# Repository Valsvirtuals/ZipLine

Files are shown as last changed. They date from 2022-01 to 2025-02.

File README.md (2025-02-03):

# ZipLine
Cheap and relatively easy to build finger tracking glove for vr
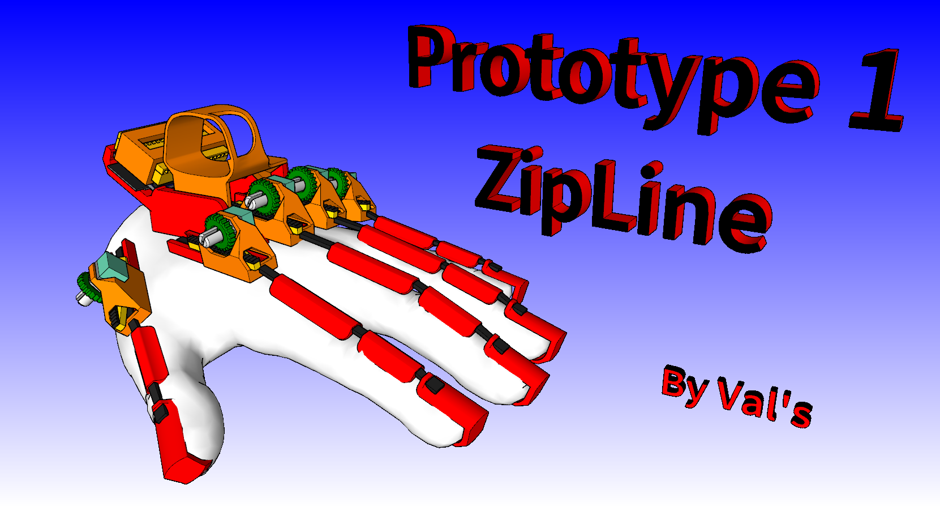
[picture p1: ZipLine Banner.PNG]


this project uses the lucid glçove firmware: https://github.com/LucidVR/lucidgloves
and the openglove driver: https://store.steampowered.com/app/1574050/OpenGloves/

/!\ THIS IS AN EALY PROTOTYPE /!\

it's far from perfect. if you just want a glove that work, this aint' it!
you've been warned.

i don't take any responsibility in your disapointment.

if you have any question don't hesitate to come and aks on my discord server in the LimenVR > #harware-help channel

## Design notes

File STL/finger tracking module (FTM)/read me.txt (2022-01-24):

dovetail parts (way & slide) sould be printed with cura ironing feature, or sililar from other slicer

the gear sould be printed at around 10mm/s print speed to preserve details

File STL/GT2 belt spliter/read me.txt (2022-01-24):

assembly:

-print the 2 parts
-glue them together
-stick a 9mm utility knife blade thought the slot, leading edge on the narrower side

usage:

-start the cut by sliting end of the belt in two
-push the plit end thought the spliter jig
-pull from the other side

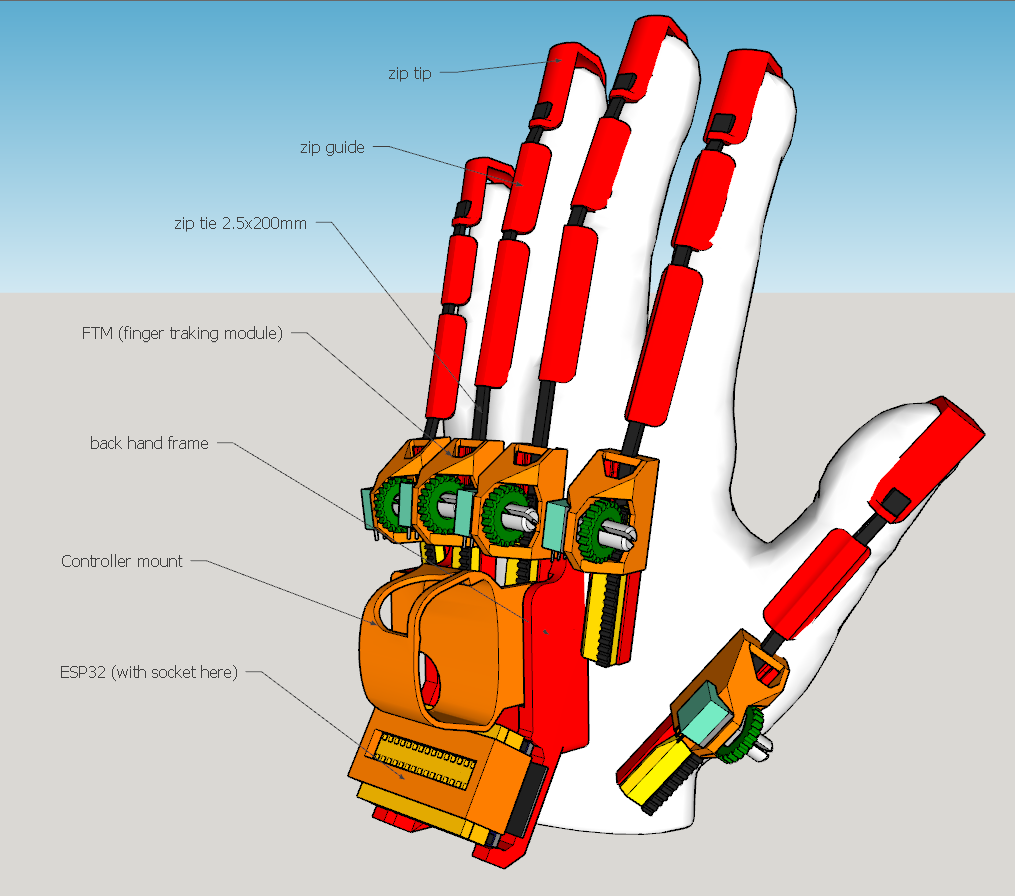
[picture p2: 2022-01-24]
description glove.PNG

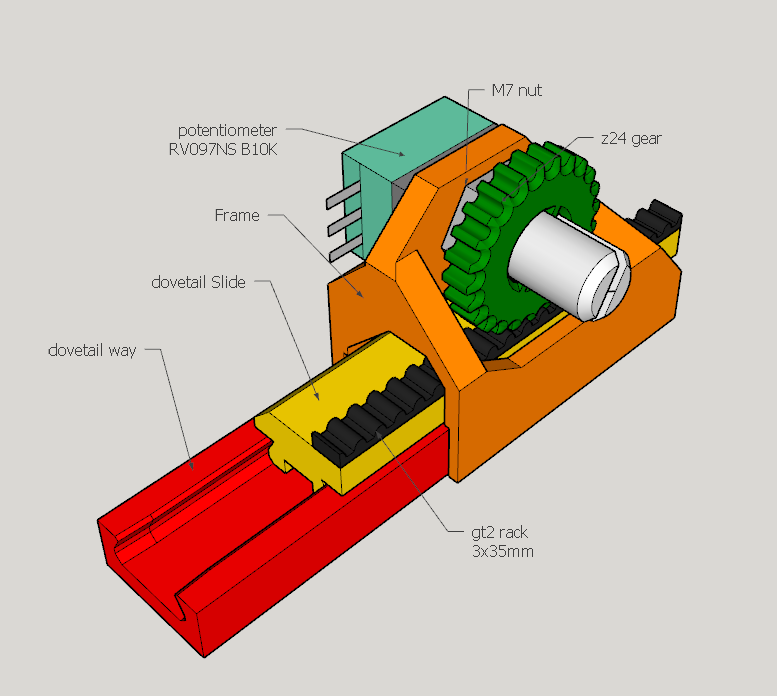
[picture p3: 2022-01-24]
description finger tracking module.PNG

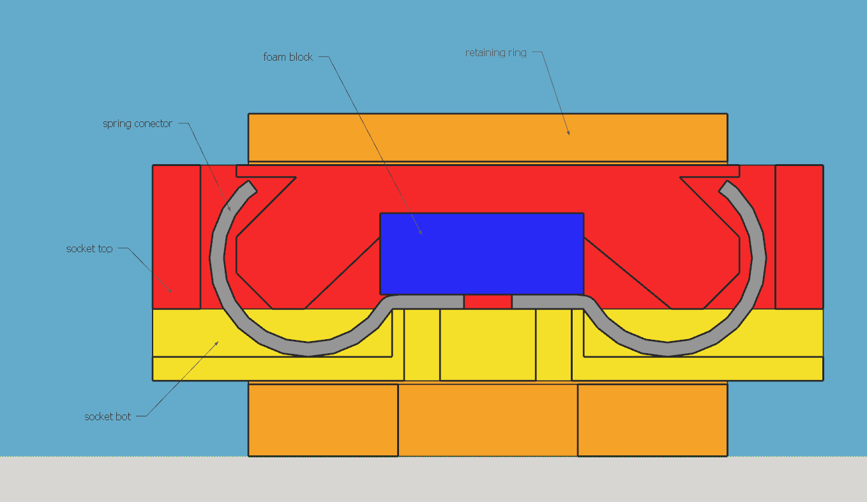
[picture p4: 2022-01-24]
ESP32 socket (optional)/socket section plane.PNG

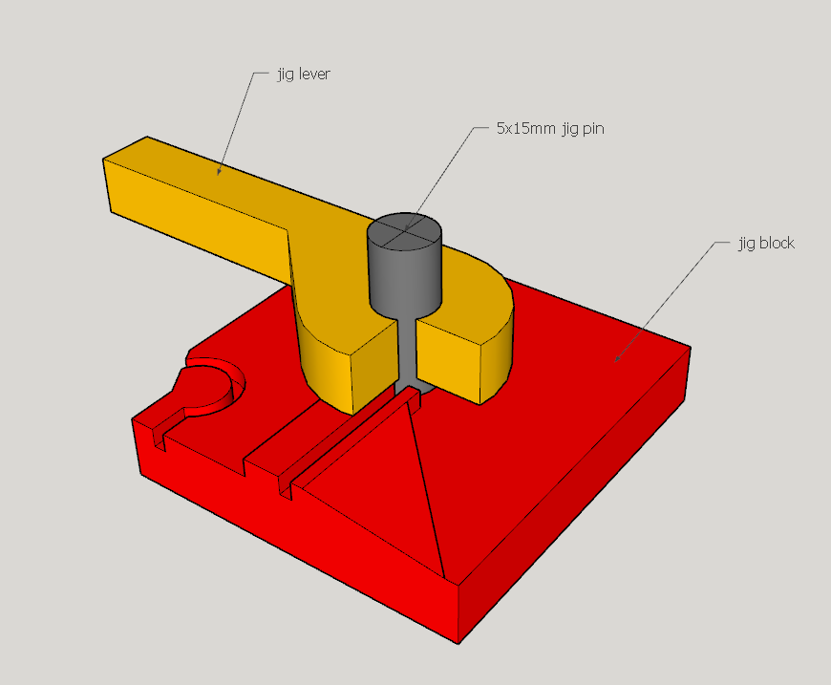
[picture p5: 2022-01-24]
ESP32 socket (optional)/connector bending and cutting jig jig.PNG

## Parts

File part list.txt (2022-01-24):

for 1 glove

what you need to get:
- Nylon glove (need to be quite thin and fit thightly on your hand)
-1x ESP32 Wroom DevKit Board
-5x RV097NS B10K Potentiometers (with nut and washer)
-5x 2.5x200mm zip ties (2.5x150mm is enough for smaller hands)

what you need to print:
-5x zip tip
-9x zip guides (chose the right size for each knuckles and fingertips)

-5x Finger tracking module:
   -5x dovetail way    (print with ironing)
   -5x dovetail slide  (print with ironing)
   -5x frames
   -5x z24 gears       (10mm/s print speed)

-1x Back Hand Frame
-1x Controller mount (windows mr or you can edit blank controller mount to fit your's)

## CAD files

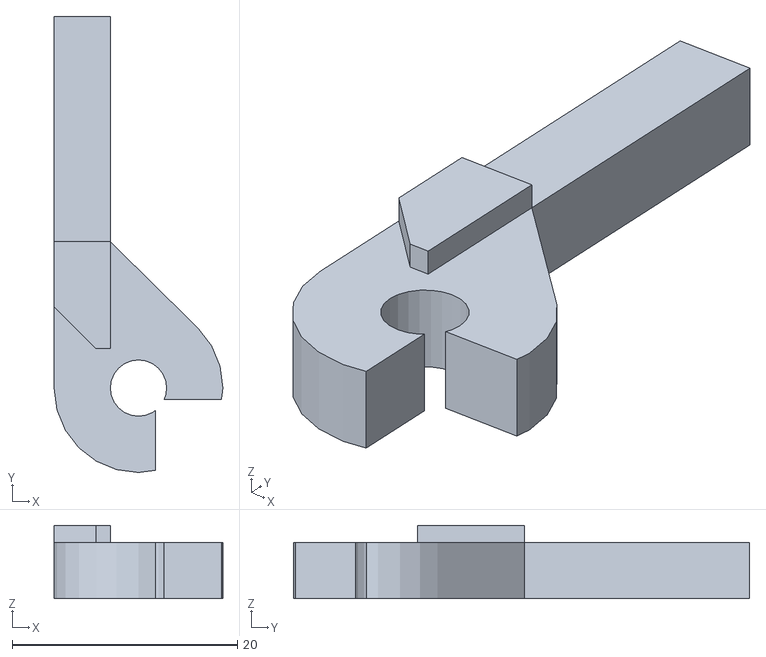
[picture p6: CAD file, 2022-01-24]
ESP32 socket (optional)/STL/Jig/esp32 socket jig lever.stl
15.0 x 40.5 x 6.50

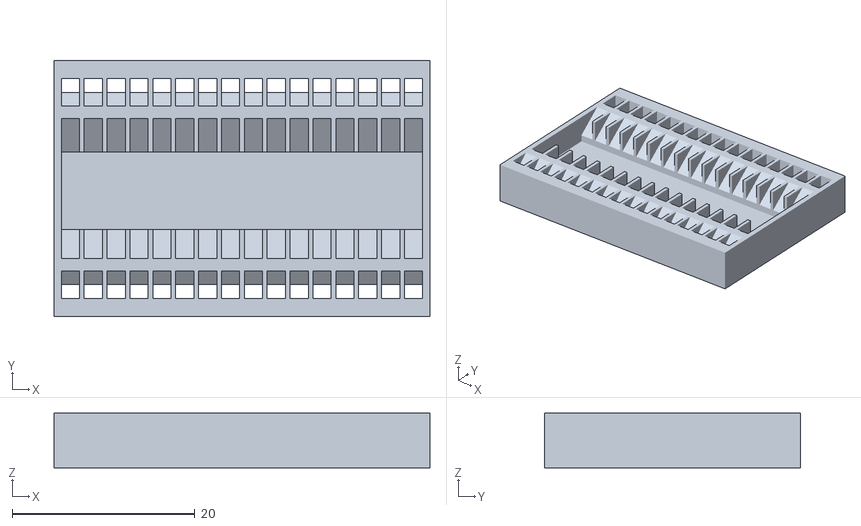
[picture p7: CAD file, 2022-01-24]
ESP32 socket (optional)/STL/Socket/esp32 socket top.stl
41.1 x 28.0 x 6.00

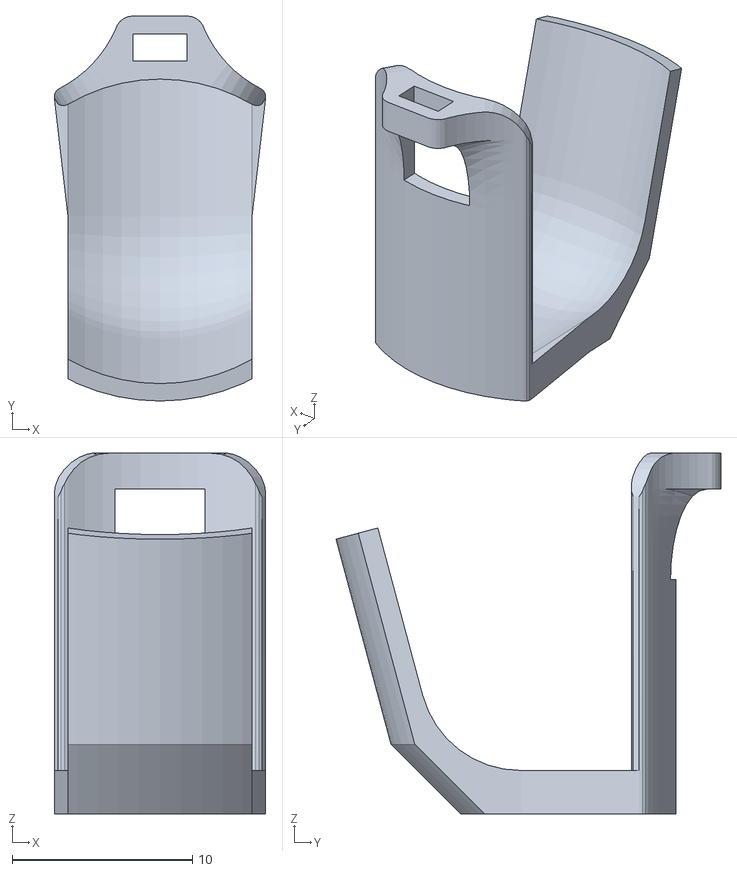
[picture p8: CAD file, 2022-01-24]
STL/finger guide/zip tip 20.stl
11.7 x 21.3 x 20.0

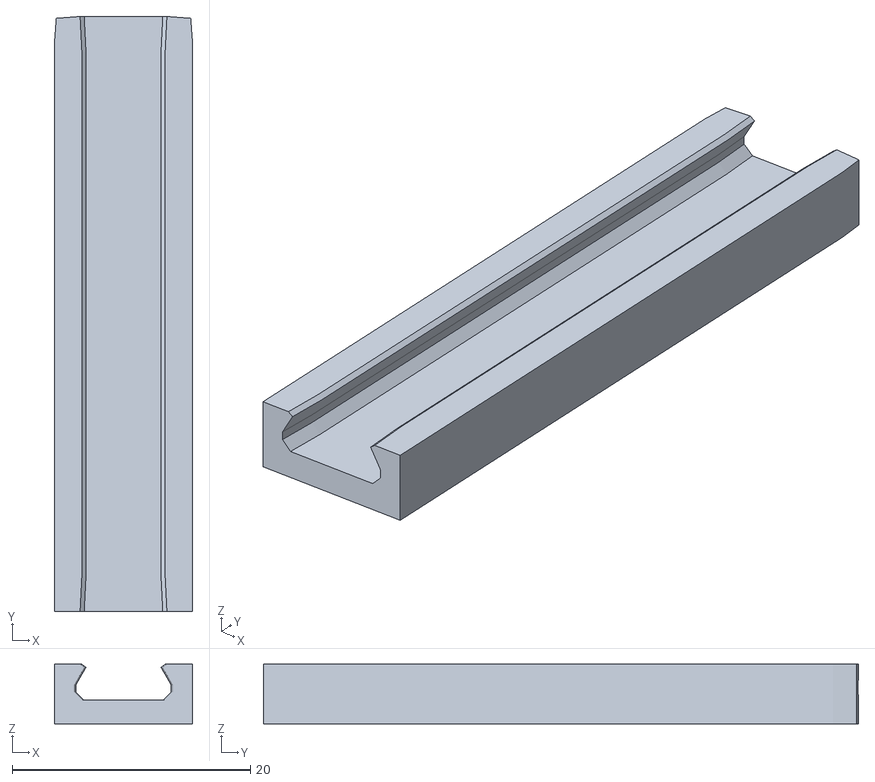
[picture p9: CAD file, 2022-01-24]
STL/finger tracking module (FTM)/dovetail way.stl
11.6 x 50.0 x 5.00

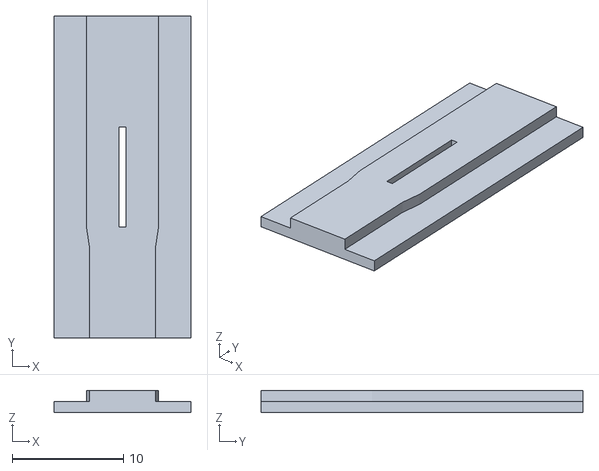
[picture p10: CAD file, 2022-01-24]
STL/GT2 belt spliter/belt spliter 2.stl
12.3 x 29.0 x 2.00

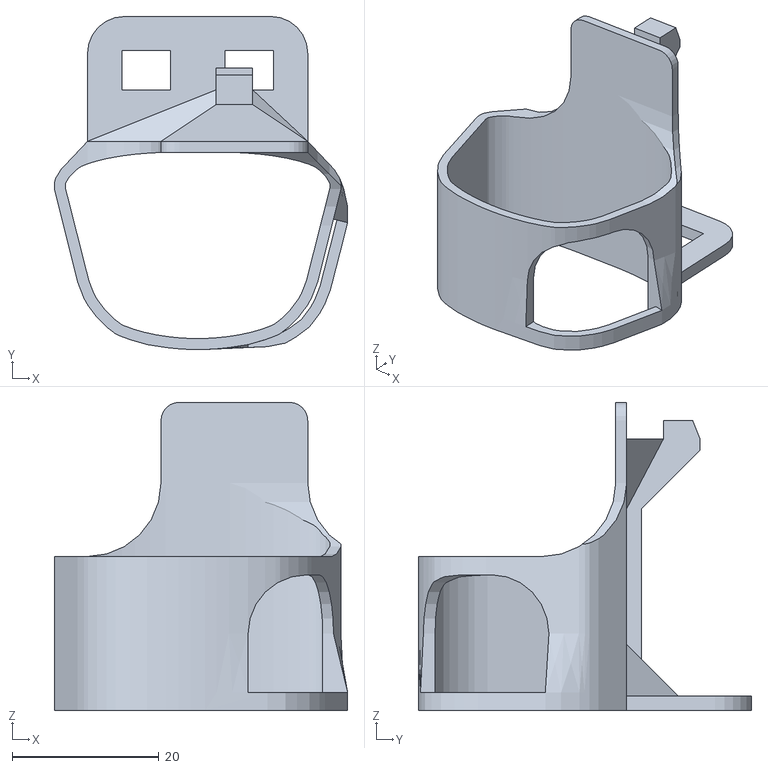
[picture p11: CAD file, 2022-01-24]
STL/Windows MR controller mount.stl
39.9 x 45.4 x 42.0

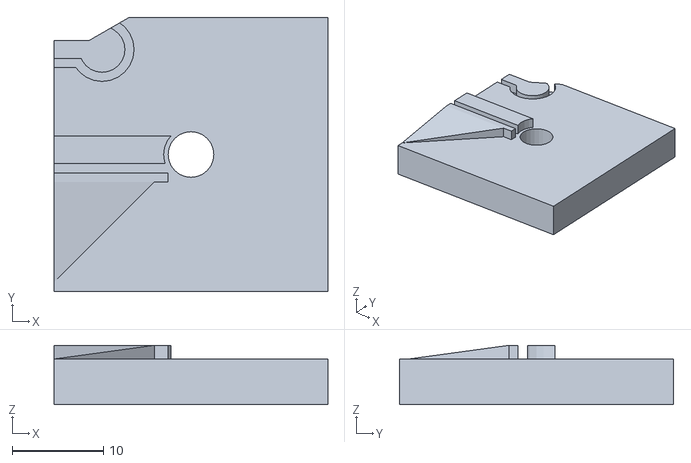
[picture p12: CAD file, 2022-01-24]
ESP32 socket (optional)/STL/Jig/esp32 socket jig block.stl
30.0 x 30.0 x 6.50

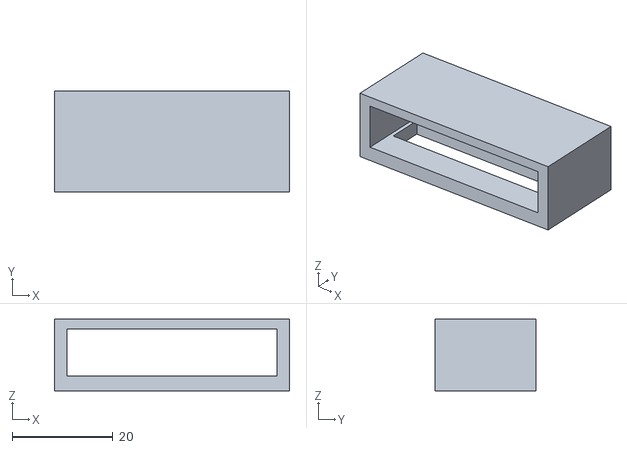
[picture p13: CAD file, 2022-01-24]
ESP32 socket (optional)/STL/Socket/esp32 socket retaining ring.stl
46.7 x 20.0 x 14.3

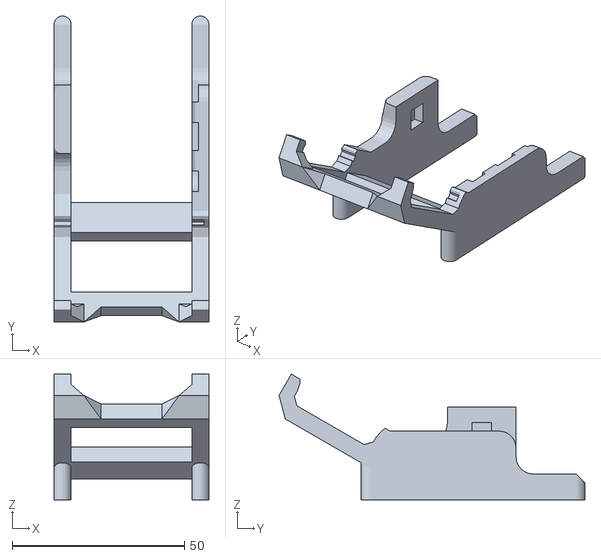
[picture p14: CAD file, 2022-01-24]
STL/esp32+controller frame.stl
45.0 x 88.9 x 36.5

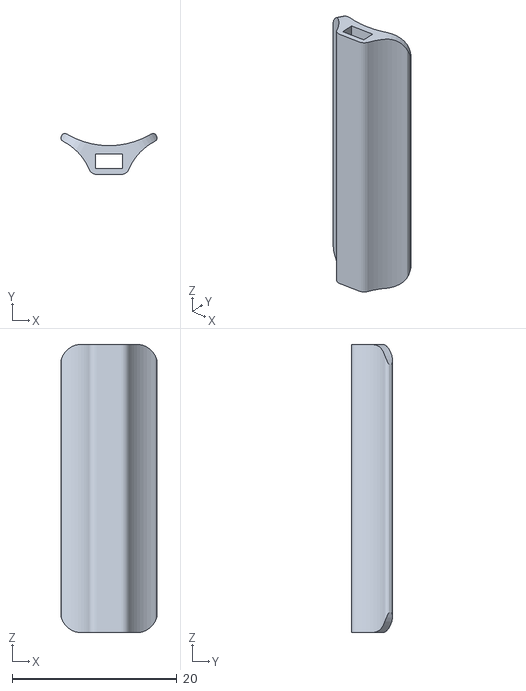
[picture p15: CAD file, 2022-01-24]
STL/finger guide/zip guide 35.stl
11.7 x 4.97 x 35.0

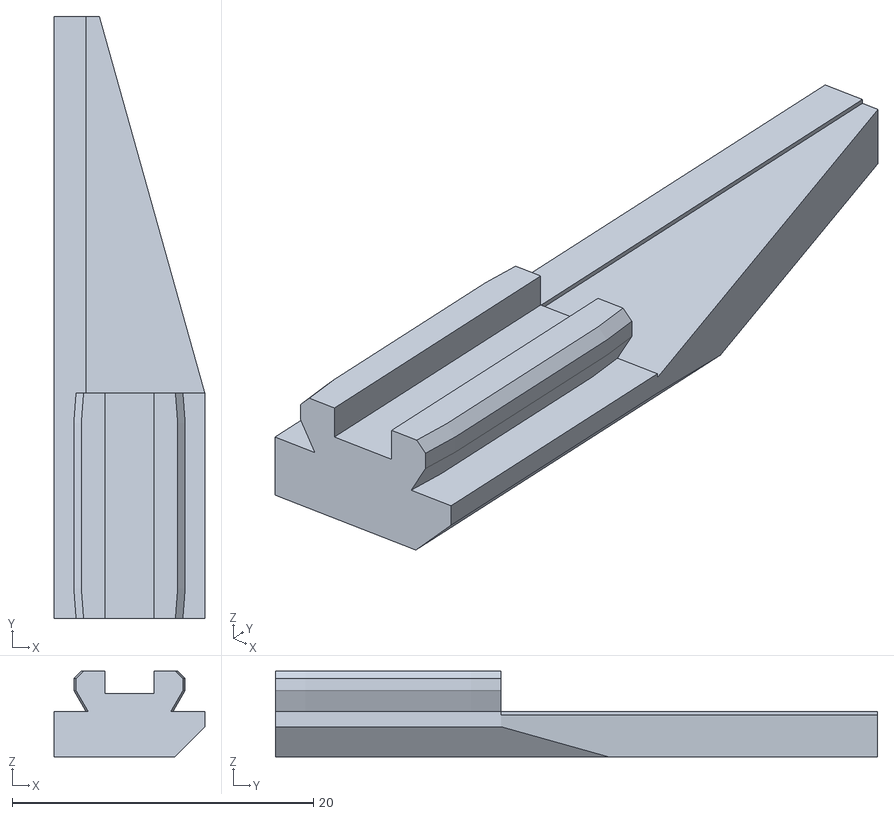
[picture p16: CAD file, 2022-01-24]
STL/finger tracking module (FTM)/dovetail slide.stl
10.0 x 40.0 x 5.70

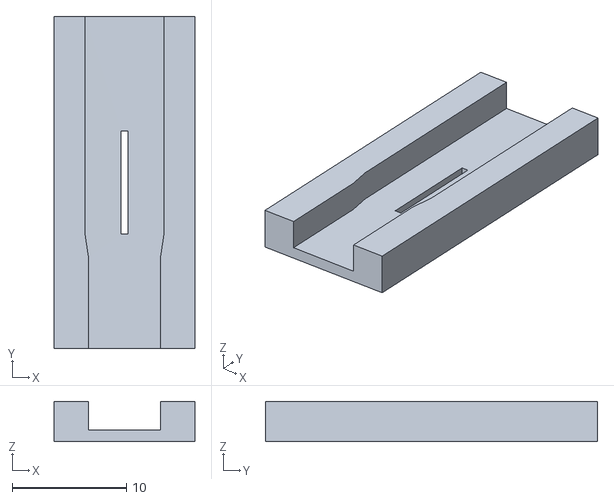
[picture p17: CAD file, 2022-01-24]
STL/GT2 belt spliter/belt spliter 1.stl
12.3 x 29.0 x 3.50

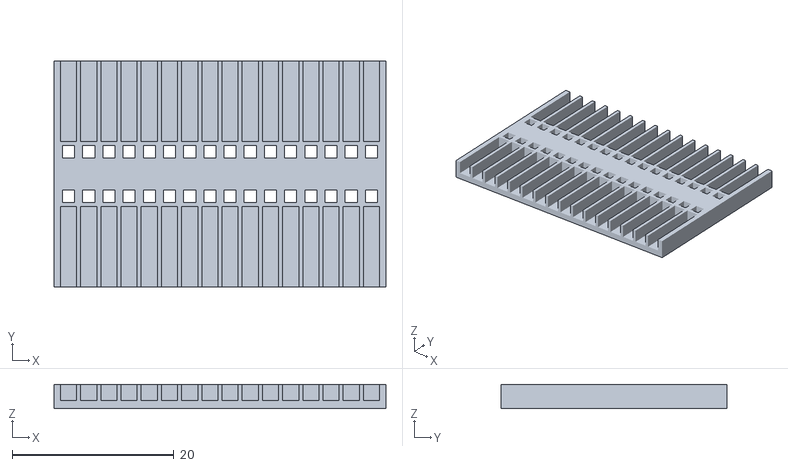
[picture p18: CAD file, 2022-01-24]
ESP32 socket (optional)/STL/Socket/esp32 socket bottom.stl
41.1 x 28.0 x 3.00

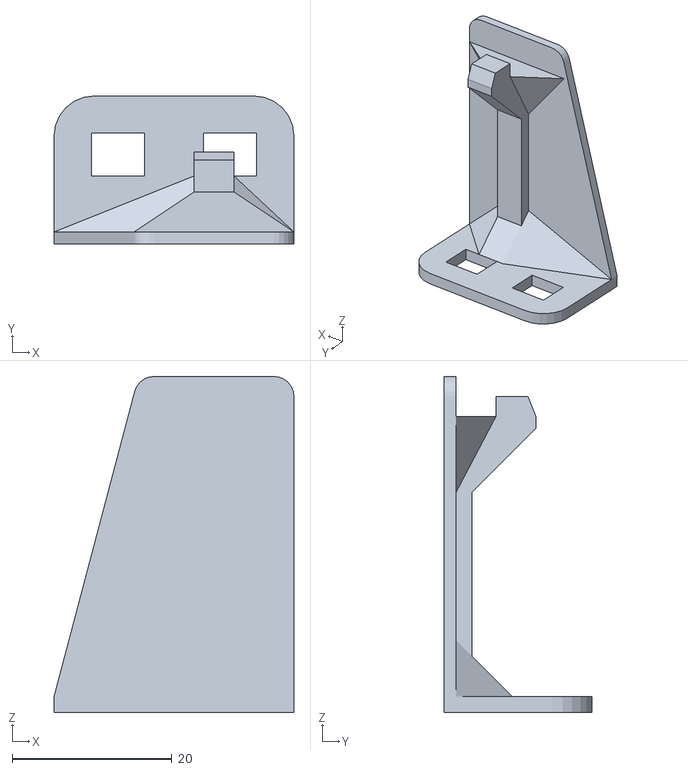
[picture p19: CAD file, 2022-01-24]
STL/blank controller mount.stl
30.0 x 18.5 x 42.0

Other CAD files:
STL/finger guide/zip guide 10.stl
STL/finger tracking module (FTM)/z24 gear.stl
STL/finger guide/zip tip 15.stl
STL/finger tracking module (FTM)/frame.stl
ESP32 socket (optional)/esp32 socket.skp
STL/finger guide/zip guide 15.stl
STL/finger guide/zip guide 20.stl
STL/finger guide/zip guide 25.stl
STL/finger guide/zip guide 30.stl
STL/finger guide/zip guide 40.stl
STL/finger guide/zip tip 10.stl
STL/finger guide/zip tip 25.stl
STL/finger guide/zip tip 30.stl
prototype 1.skp

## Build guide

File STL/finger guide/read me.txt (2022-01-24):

zip knuckle guides and fingertips aviable in lengh ranging from 10 to 30mm in 5mm increment to acomodate various hand size

guide lengh should be about 5mm shorter than the knuckle it is gonna be on

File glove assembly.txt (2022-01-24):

===============
PART 1: Fingers
---------------
1- slide the zip ties on every "zip tips",the head of the zip tie should face down and snap in place,
   once secured it will then stick out inside of the "zip tip", cut the exece of th"e head where it would interfeer with your finger.

2- put on the glove and hot glue the "zip tip" to the end of one of the gloves finger.
   after apllying the hot glue, wait to let the glue cool down a bit so that you don't burn yourself.

3- slide on the first "zip guide", apply hot glue, close your fist for better alignement and then stick the "zip guide" well centred on the next knuckle,
   do the same for the next "zip guide" (exept for the thumb). Repeat step 2&3 for each finger.

==============================
PART 2: Finger Tracking Module
------------------------------
4- "dovetail slide" sloud be able to slide freely in "dovetail way", if it is not make sure there is no defect on the sliding surfaces,
   then sand the top of "dovetail way" with 180 grit(or higher) sand paper, a bit of graphite frome a pencil can help .

5- super glue a small section of gt2 belt (3x35mm) onto the long side of the top of "dovetail slide"

6- bolt the potetiometers onto "FTM frame", press "z24 gear" onto the shaft of the potentiometer, as shone in "description finger tracking module.png".
   depending on your finger spacing, you might need to cut of the excess leght of the shaft on 3 potentiometer,
   use a hacksaw and cut slowly as to not make any heat buildup.(it is also advised to lubricate your potentiometers before step 5)

7- with the glove on, position "dovetail way"(with dovetail slide on it) on the back of the hand aligned to a finger.
   the zip tie sould fit in the dovetail, in the track at the bottom of "dovetail slide".
   close your fist, aligne the front of "dovetail slide" to the front of "dovetail way",
   mark the zip tie at the back of "dovetail slide" (paint pen work well) and cut the zip tie to lengh.

8- slide "FTM frame" onto the zip tie, make sure it is in the right orientation.
   glue the end of the zip tie to "dovetail slide" with super glue , make sure it is in the right orientation.
   wipe excess glue and wait for it to fully set.

9-slide "dovetail way" onto "dovetail slide" and in position in "FTM frame".make sure the rack and pinion mesh properly and with a few drops
  of super glue from the bottom, glue "dovetail way" onto "FTM frame" make sure to NOT glue "dovetail slide" for obvious reasons.

10-with the glove on, fist closed, "dovetail slide" all the way forward, hot glue the finger tracking module inline with the finger it's attached to,
   making sure there is enough space left for "back hand farme" Repeat step 7 to 10 for each finger.

================
Part 3: the rest
----------------
11-hot glue "back hand frame" to the back of the hand, slide the esp32 in place and secure it with a small blob of hot glue on two opposing corner,
   snap on the controller mount

12-wiring, should be the same as LucidVR prototype3, this is also when you can add your own joystick and buttons.

13-lubrication, put a drop of light machine oil o the "dovetail way", "z24 gear" and "zip guide" and move things for a bit

14-sideload the firmware onto the esp32 and enjoy your glove :)

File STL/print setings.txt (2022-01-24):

-pla
-0.2mm layer height
-50% infill
-2 perimeters
-3 top/bot layer
-tree support
